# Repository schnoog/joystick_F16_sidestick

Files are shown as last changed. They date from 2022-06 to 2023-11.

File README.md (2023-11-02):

# My F16 Sidestick

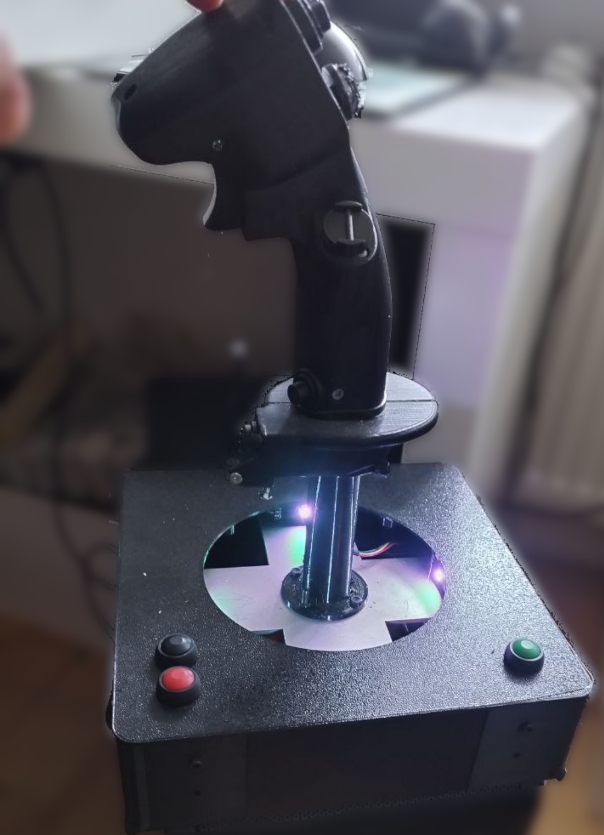
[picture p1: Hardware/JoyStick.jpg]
Joystick


This repository holds (almost) all the information about my DIY F16 Force Sensing Sidestick I use mainly in DCS

The stick itself is printed from **https://www.thingiverse.com/thing:4544115**

I used different switches (navigation switches which I had laying around together with fitting PCBs. If those wouldn't have already existed in my drawer I would have used the switch designs included in the Thingiverse project.

My initial version was based on the well known olukelo gimbal with hall effect sensors, so I used the adapter I had on the gimbal for my force sensing approach too.

## Components
beside the F16 Grip & Adapter
### Mechanic components
**Metal parts**
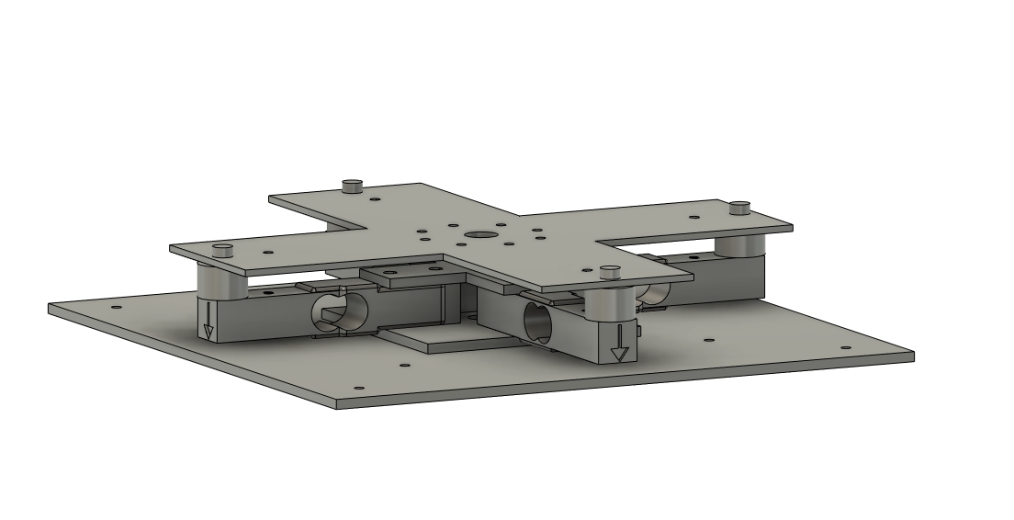
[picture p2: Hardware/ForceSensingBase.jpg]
Alu parts


* **1x Ground plate** (BodenPlatte.dxf)
* **1x Ground distance plate** (BodenDist.dxf) - ensures distance between the load cells and the ground plate)
* **1x Top cross** (Topkreuz.dxf) -connects the upper sides of the load cells in the center)
* **1x Top plate** (Joyplate.dxf) 

I ordered the aluminum parts at Xometry made out of 3mm sheets of EN AW-6060 / 3.3206 / Al-MgSi
All 4 parts in the folder Hardware\Metal_parts together came with a total order value of  68.78 Euro

**Other**

* A unknown amount of M4 and M3 screws and nuts ;)
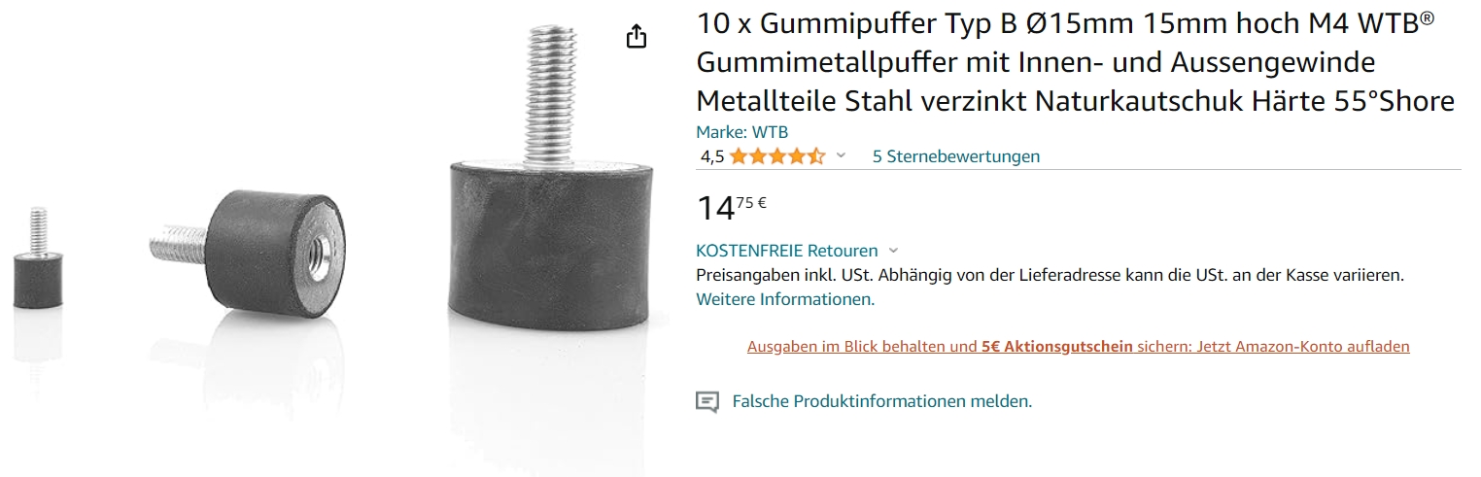
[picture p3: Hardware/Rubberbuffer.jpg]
Buffer
* **4 rubber buffers** (15mm diameter, 15mm lenght, M4 screw thread 

**Load cells**

* **4 x 80mm Load Cells** (mine are 3kg, but that's personal preference). Be aware that **there are 80mm and 75mm versions available, I designed it using the 80mm** I already had at home 

### Case
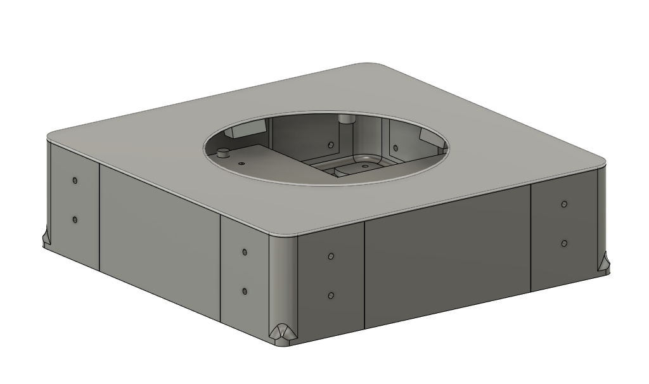
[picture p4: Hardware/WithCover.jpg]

The case consists of 
* 4 **Side parts** (Seiten_thin.stl - all 4 attached together)
* 4 **Corners** (Ecken_thin.stl- all 4 attached together)
* 1 **Lid** (Deckel_nd.stl)

The lid has small ramps to which I attached 4 WS2812B LEDs I cut from a strip I had laying around.

### Electronics

* **Arduino Pro Micro (Clone)** If you need to buy one, be sure to buy one with 5V (there are 3.3V and 5V available) and USB-C socket (the damn micro USB sockets are only SMD attached to the circuit boad and rip off easily)

* **1x ADS1115 16bit ADC Modul** for example by AZ delivery. But there are dozen other manucaturers which use the same board layout (ADS1115.jpg)
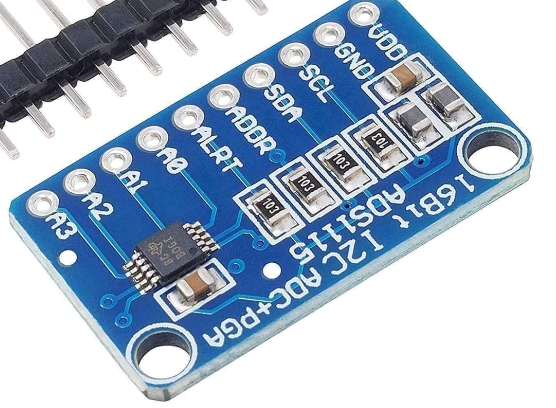
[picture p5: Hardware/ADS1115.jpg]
ADS1115

* **2x MCP 23017 IO Expander moduls**  
* **2x INA 122P instrument amplifier** (I used sockets, but can be soldered directly to the PCB
* **1x Potentiometer >=10k type  3296 - 3/8 ? Square Trimpot** 
* **2x Potentiometer (same 3296 type, but 100 or 200 Ohm)**

* **1x Base PCB** That's the printed circuit board which holds all components in the base. 
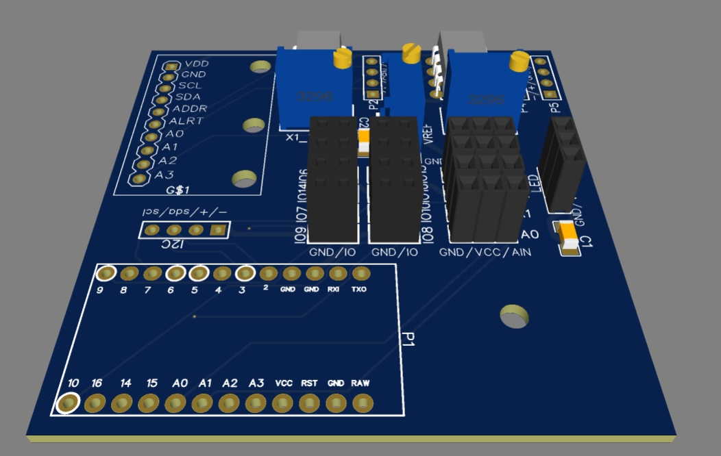
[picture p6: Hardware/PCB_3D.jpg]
PCB

(the PCB has some additional ports, for up to 4 analog and 8 digital inputs, I connected 3 additional digital inputs to buttons. One for recalibration of the center position and noise and 2 for ingame functions)

**Stick internal wiring**

Internally all the buttons in the stick are wired up to 2 MCP23017 boards (as shown in Wire-connection.png). That means I only have 4 wires going out of the joystick into my PCB
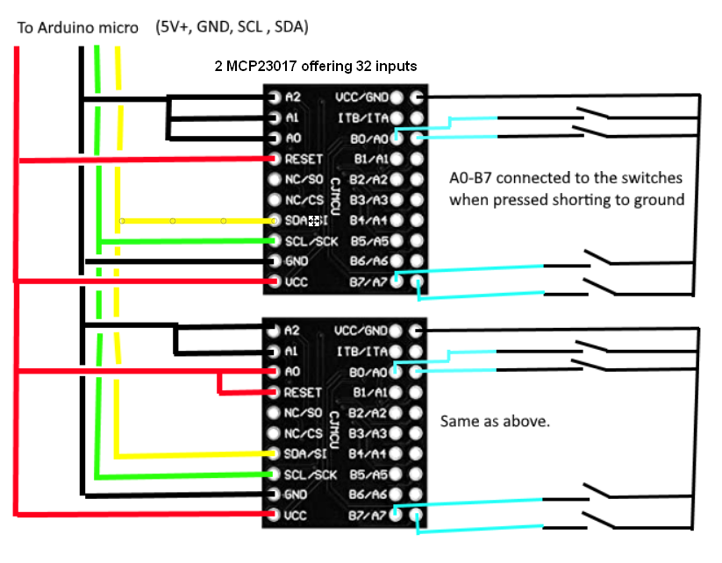
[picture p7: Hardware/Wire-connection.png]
Wiring


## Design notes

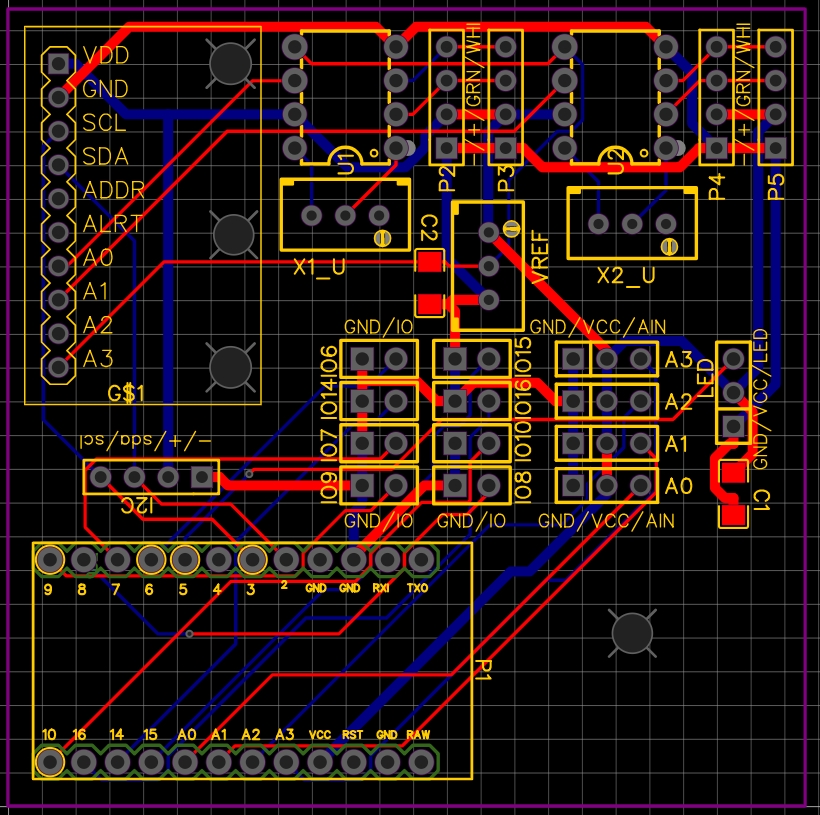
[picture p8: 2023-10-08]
Hardware/PCB.jpg

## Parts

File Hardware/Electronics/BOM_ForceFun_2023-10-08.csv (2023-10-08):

ID | Name | Designator | Footprint | Quantity | Manufacturer Part | Manufacturer | Supplier | Supplier Part | Price
1 | 0.1u | C1,C2 | C1206 | 2
2 | ADC-4CH-ADS1115 | G$1 | ADC-4CH-ADS1115 | 1
3 | Pro Micro - 5V | P1 | PRO MICRO - 5V | 1
4 | Header-Female-2.54_1x4 | P2,P3,P4,P5,P7 | HDR-4X1/2.54 | 5 | Header-Female-2.54_1x4 | ReliaPro | LCSC | C124413 | 0.114
5 | Header-Female-2.54_1x3 | P6,P8,P9,P10,P11 | HDR-TH_3P-P2.54-V-F | 5 | 2.54-1*3P母 | BOOMELE(博穆精密) | LCSC | C146243 | 0.057
6 | Header-Female-2.54_1x2 | P12,P13,P14,P15,P16,P17,P18,P19 | HDR-TH_2P-P2.54-V-F | 8 | 2.54-1*2P母 | BOOMELE(博穆精密) | LCSC | C49661 | 0.035
7 | 10kΩ | R1,R2,R3 | RES-ADJ-TH_3296W | 3 | 3296W-1-103LF | BOURNS | LCSC | C83687 | 0.845
8 | INA122P | U1,U2 | PDIP-8_L9.6-W6.4-P2.54-LS7.6-BL | 2 | INA122P | TI(德州仪器) | LCSC | C1346816 | 22.815

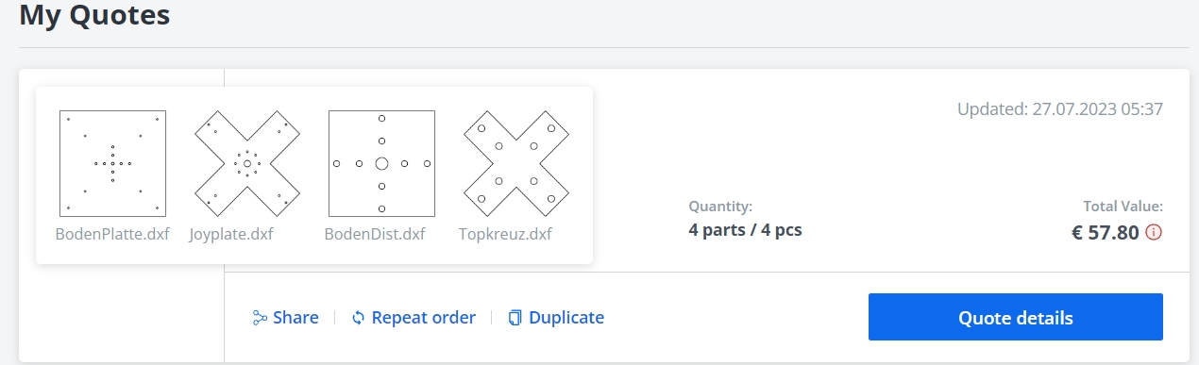
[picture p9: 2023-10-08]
Hardware/Metal parts/Xometry_order.jpg

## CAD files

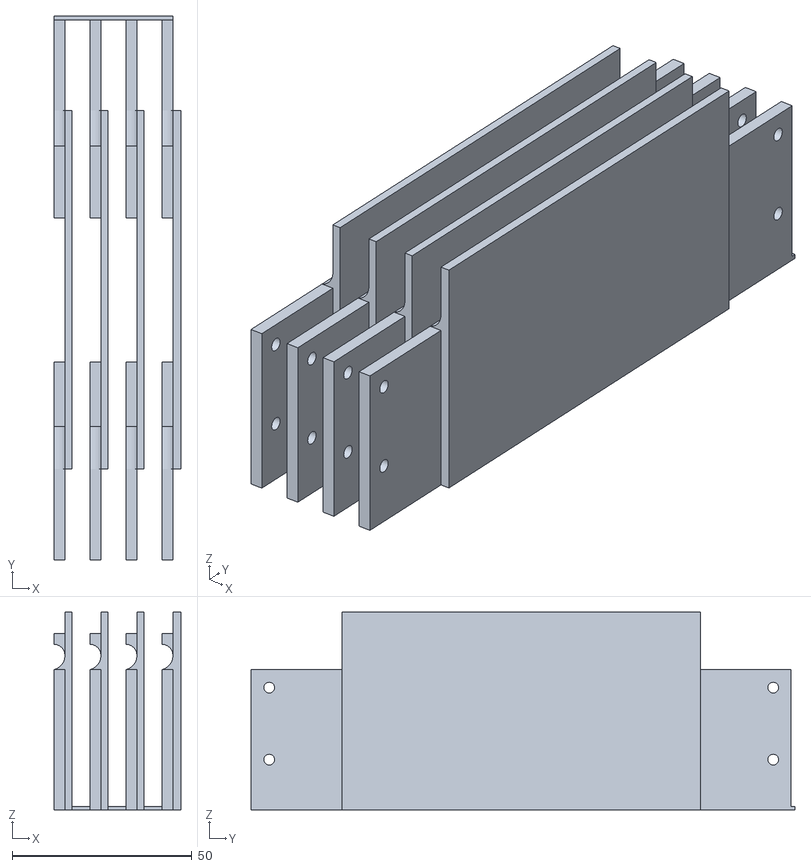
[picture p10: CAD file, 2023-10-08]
Hardware/3D printed parts/Seiten_thin.stl
35.2 x 151.0 x 55.0

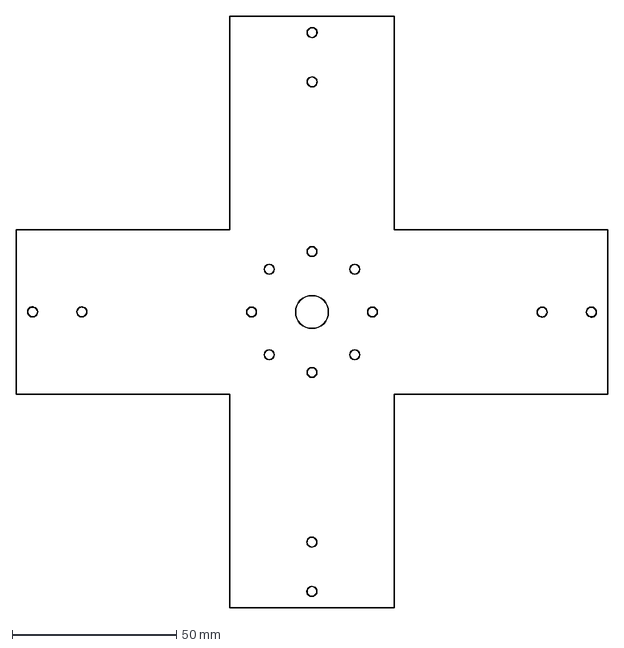
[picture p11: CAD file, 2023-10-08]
Hardware/Metal parts/Joyplate.dxf
180.0 x 180.0 mm

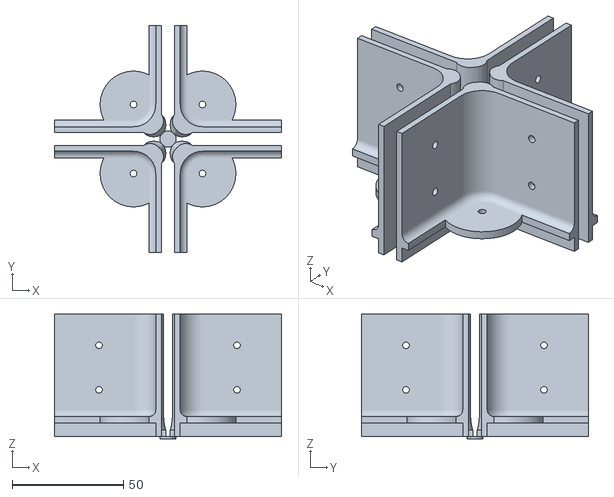
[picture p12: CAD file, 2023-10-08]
Hardware/3D printed parts/Ecken_thin.stl
102.0 x 102.0 x 56.0

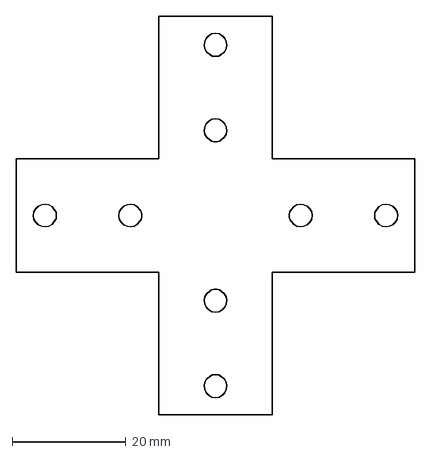
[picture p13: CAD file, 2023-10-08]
Hardware/Metal parts/Topkreuz.dxf
70.0 x 70.0 mm

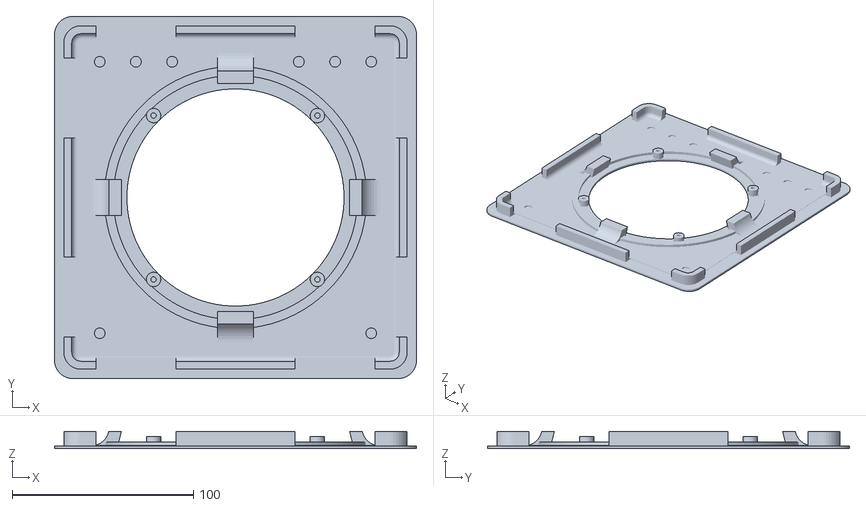
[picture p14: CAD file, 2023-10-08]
Hardware/3D printed parts/Deckel_nd.stl
200.0 x 200.0 x 9.60

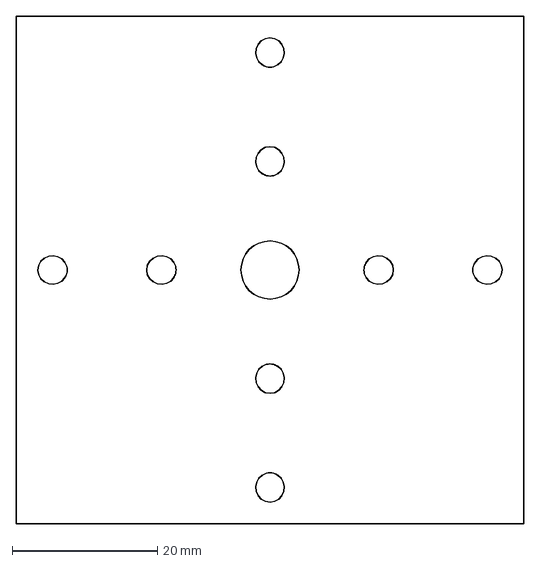
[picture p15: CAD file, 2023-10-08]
Hardware/Metal parts/BodenDist.dxf
70.0 x 70.0 mm

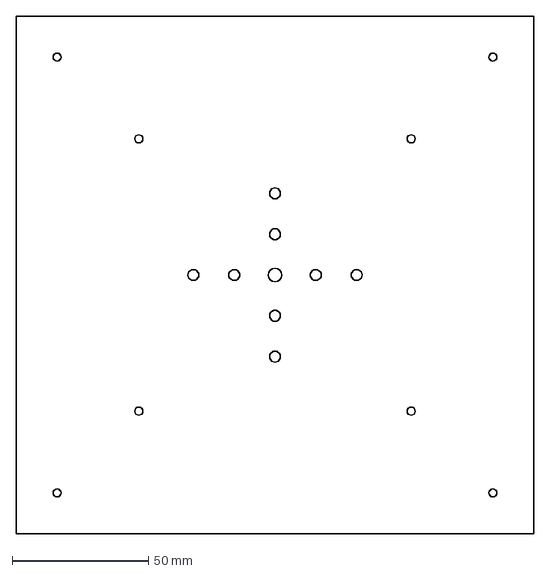
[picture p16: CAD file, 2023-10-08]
Hardware/Metal parts/BodenPlatte.dxf
190.0 x 190.0 mm

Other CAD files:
Hardware/Joystick_ForceSensingBase.f3d

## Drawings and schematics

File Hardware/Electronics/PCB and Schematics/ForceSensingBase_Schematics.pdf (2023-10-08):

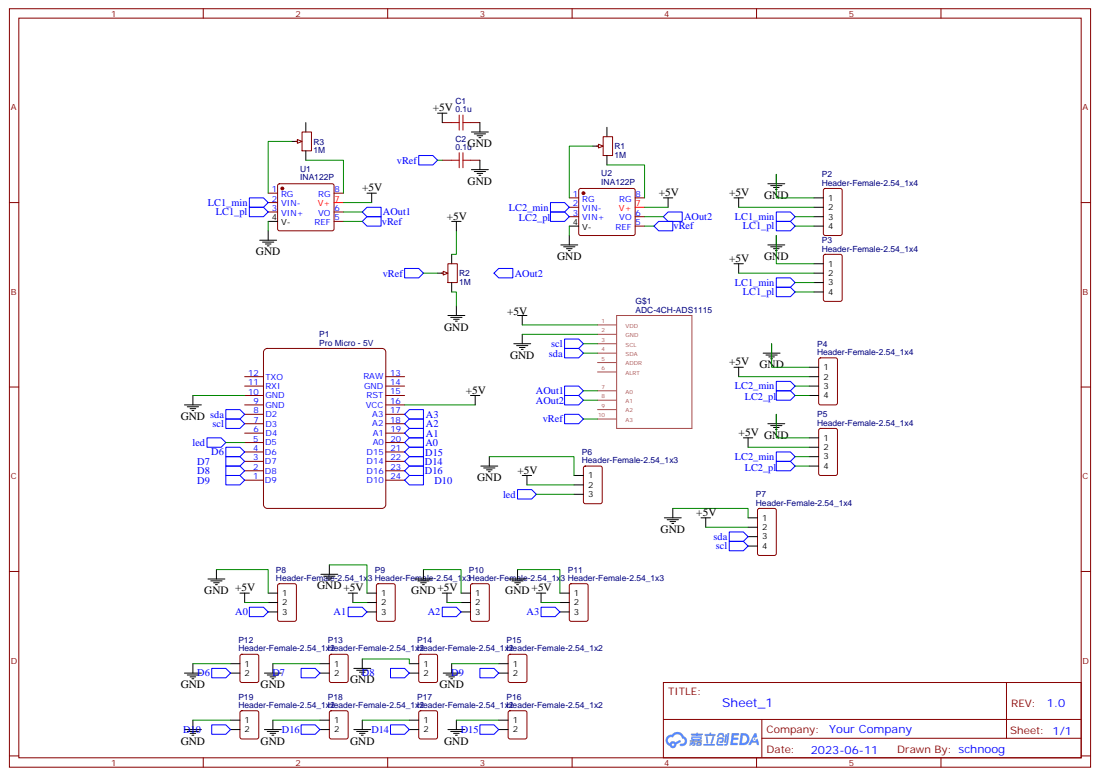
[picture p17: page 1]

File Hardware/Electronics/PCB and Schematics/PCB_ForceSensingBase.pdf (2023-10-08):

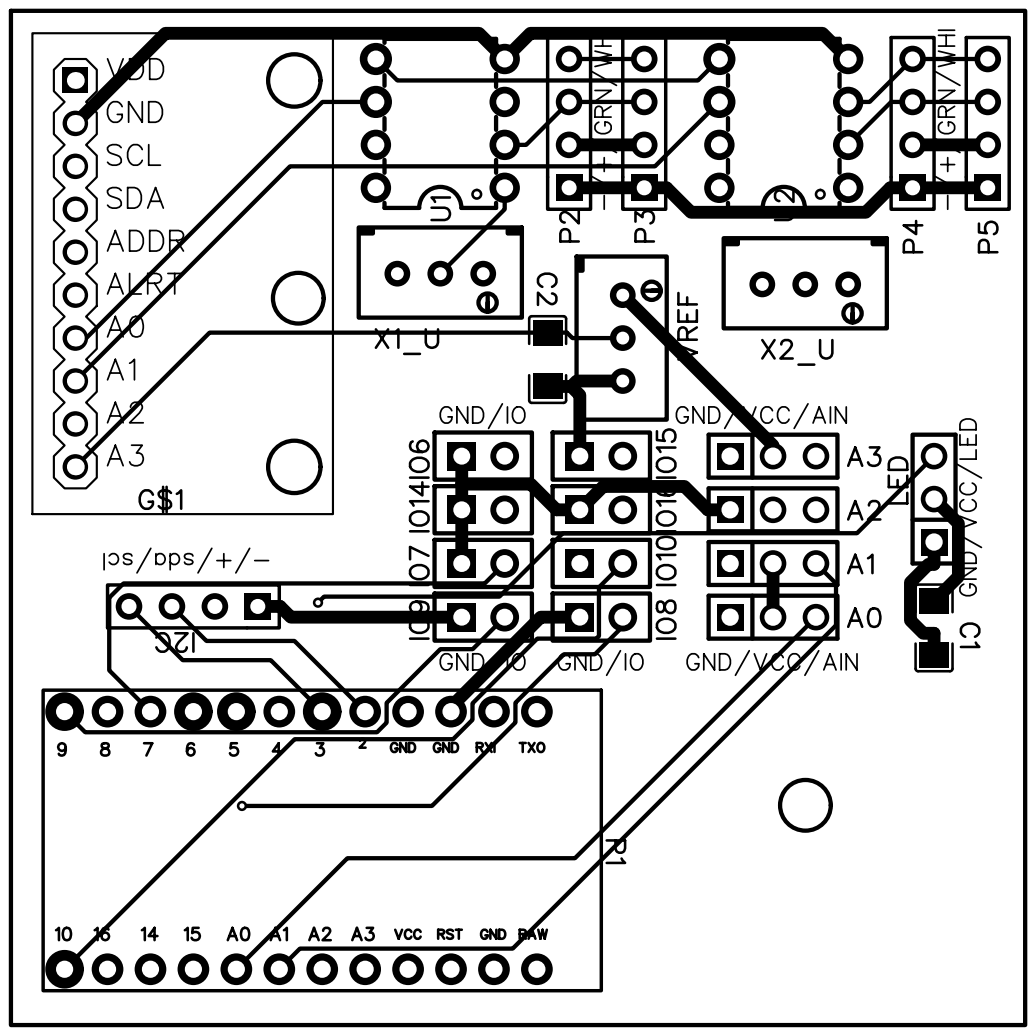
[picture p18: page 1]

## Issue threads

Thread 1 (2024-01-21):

Help F-16 sidestick

gambiarra-eng, 2024-01-21:
Hello, Volker,how are you?
I hope you are well!
I am from Brazil!
I really liked your excellent project, please I have some questions, sorry for my questions, I don't have much knowledge of electronics!
I have 20Kg load cells, I have the HX 711, INA 122P, ADS 1115 16 bit i2c and the MCP23017, please what would the connections be like?
What would be the values to be implemented in tres Trimpots.
I had your PCB made at JLCPCB and I have already received them, please what are the values of resistors C1 and C2?
Thanks for any help!
gambiarra

schnoog, 2024-01-22:
Hi gambiarra, thanks doing fine, hope you too.

C1 and C2 are only for some stabilisation. I used 0.1uF SMDs I had laying around. They aren't required for operation.

In regards to the pots:

The one (Vref) should be tuned so that on A3 of the ADS1115 2.5V can be measured (or to be more explicit: Half the power supply voltage).

The other both define the amplification of the 2 axis. Therefore it's difficult to define an exact setting.
How I have done it:

I placed my stick on a desk, attached a small thread on the higher part of it. On the other side of the thread I attached a 2kg weight (so that roughly 2kg were pulling on the joystick). Then I tuned the pot to have a full output signal (one direction to 0, the other to 32767) for both axis.

I really hope this help you. Please don't hesitate to ask if you have further questions.

Closed 2024-01-27.

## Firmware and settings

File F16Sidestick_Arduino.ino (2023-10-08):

#include "settings.h"
#include "init.h"


//ADS1115 ADS(0x48);



long LPS=0;


///---setup
void setup() {
  Serial.begin(9600);
  pinMode(6, INPUT_PULLUP);
  pinMode(7, INPUT_PULLUP);
  pinMode(14, INPUT_PULLUP);
//  while (!Serial); // Leonardo: wait for serial monitor
  LED_setup();
  mcp1.begin(addr1);      // use default address 0
  mcp2.begin(addr2);

    for (int i=0; i < 16; i++) {
          mcp1.pinMode(i, INPUT);
          mcp1.pullUp(i, HIGH);  // turn on a 100K pullup internally
          mcp2.pinMode(i, INPUT);
          mcp2.pullUp(i, HIGH);  // turn on a 100K pullup internally
    }
    ADS_Setup();
//    ADS.begin();
//    ADS.setGain(0);
// if(!adc.init()){
//    Serial.println("ADS1115 not connected!");
// } //else{
//  adc.setVoltageRange_mV(ADS1115_RANGE_6144); 
//  }

//    int BaseReadX = (int) ADS.readADC(0);
//    int BaseReadY = (int) ADS.readADC(1);
//    int MidOff = 12750;
//    Joystick.setXAxisRange( BaseReadX + MidOff, BaseReadX - MidOff);
//    Joystick.setYAxisRange(BaseReadY - MidOff, BaseReadY + MidOff);

    Joystick.setXAxisRange( 27000, 0);
    Joystick.setYAxisRange(0, 27000);
    GetCenter();  
}

///----setup



void GetButtons(){
        int ButtonA = 0;
        int ButtonB = 16;
        int mcppins  [] = {0,1,2,3,4,5,6,7,8,9,10,11,12,13,14,15};
        for (int i=0; i<sizeof mcppins/sizeof mcppins[0]; i++) {           
            int s = mcppins[i];
            debounceVal(ButtonA,(int) !mcp1.digitalRead(s));
            ButtonA++;          
        }
        for (int i=0; i<sizeof mcppins/sizeof mcppins[0]; i++) {           
            int s = mcppins[i];
            debounceVal(ButtonB,(int) !mcp2.digitalRead(s));
            ButtonB++;
        }
        int CV = 0;
        CV = (int) !digitalRead(7);
        if( CV != 0){
            if(LPS == 0) LPS = millis();
            long NOW = millis();
            int WT = 200;
            if( abs(NOW - LPS) > 700 ){
                    Joystick.setButton(33,1);
                    Joystick.sendState();
                    delay(WT);
                    Joystick.setButton(33,0);
                    Joystick.sendState();
                    delay(WT/2);
               
            }
        }else{
          LPS=0;
        } 
        debounceVal(34, (int) !digitalRead(14));
}

void GetAxis(){



//        int AX = (int)ADS.readADC(0);
//        int AY = (int)ADS.readADC(1);
        //analogReference(INTERNAL);
        MyAdsloop();
        ReadLoadCell();

        int AX =  CorrectedAxis1;
        int AY = CorrectedAxis2;
        Joystick.setXAxis(AX);
        Joystick.setYAxis(AY);  

        if(CyclesSinceCalib > StartAxisOutputAtCycle){

        debug("Axis: ");
        debug(AX);
        debug(" ,  ");
        debug(AY);
        debug("   Raw:");
        debug(VALUE_X);
        debug(" (");
        debug(Center_Axis1);
        debug(") ");
        debug(" ,  ");
        debug(VALUE_Y);
        debug(" (");
        debug(Center_Axis2);
        debug(") ");

        debug(" Voltage:");
        debug(val0[3]);
        int DZD1 = abs(Center_Axis1 - VALUE_X);
        int DZD2 = abs(Center_Axis2 - VALUE_Y);

        debugln(" Deadzone:" + (String)DeadZone + " diff: " + (String)DZD1 + " " + (String)DZD2 );

        }else{
          CyclesSinceCalib++;
        } 
}

void debounceVal(int BtnNum, int CurrentVal){
            reading = (byte)CurrentVal;
            if (reading == switch_state[BtnNum]) debounce_time[BtnNum] = millis() + (unsigned long)DEBOUNCE_TIME;
            else if (millis() > debounce_time[BtnNum]) switch_state[BtnNum] = reading;
            if (switch_state[BtnNum] != switch_state_old[BtnNum]) { // debounced button has changed state

              Joystick.setButton(BtnNum,CurrentVal);
//              Joystick.pressButton(BtnNum);
              debug("press button");
              debugln(BtnNum);
              switch_state_old[BtnNum] = switch_state[BtnNum]; // store new state such that the above gets done only once
            }
}




void loop() {
  buttonState = digitalRead(6);
  if (buttonState == 0){
      debugln("recalib");
      delay(2000);
      Center_Axis1 = 0;
      Center_Axis2 = 0;
      GetCenter(); 
      debugln("done");

  }
    GetAxis();
    GetButtons();
    Joystick.sendState();
    ApplyState();
  //Serial.println("Loop");
 // MCP_LoopA(); 
 //   ADS_Loop();
 // delay(500);
  // put your main code here, to run repeatedly:

}

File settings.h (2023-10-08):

#pragma once

#define DEBUG 1
#define DEBOUNCE_TIME 5 

const uint8_t addr1 = 0; // Adresse 0x20 / 0
const uint8_t addr2 = 1; // Adresse 0x21 / 1


#define LED_PIN     5
#define NUM_LEDS    4
#define BRIGHTNESS  128
#define LED_TYPE    WS2812B
#define COLOR_ORDER GRB
#define UPDATES_PER_SECOND 100

#define ALARM_OFF 50
#define ALARM_ON 100


int color_noinput[3] = {0,0,0};
int color_alert[3] = { 255,0,0};
int color_ok[3] = { 34,139,34};
int color_limit[3] = { 255,84,0};


int SetRed = 0;
int SetBlue = 0;
int SetGreen = 0;

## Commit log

2021-12-22 boards.txt updated, now selectable in arduino menue
2022-06-05 Wiring added
2023-06-15 weight cells on INA122P for axis, LED for overload warning
2023-06-19 center calibration and deadzone calculation
2023-10-08 Everything updated
    [BOM_ForceFun_2023-10-08.csv, BodenDist.dxf, BodenPlatte.dxf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]
